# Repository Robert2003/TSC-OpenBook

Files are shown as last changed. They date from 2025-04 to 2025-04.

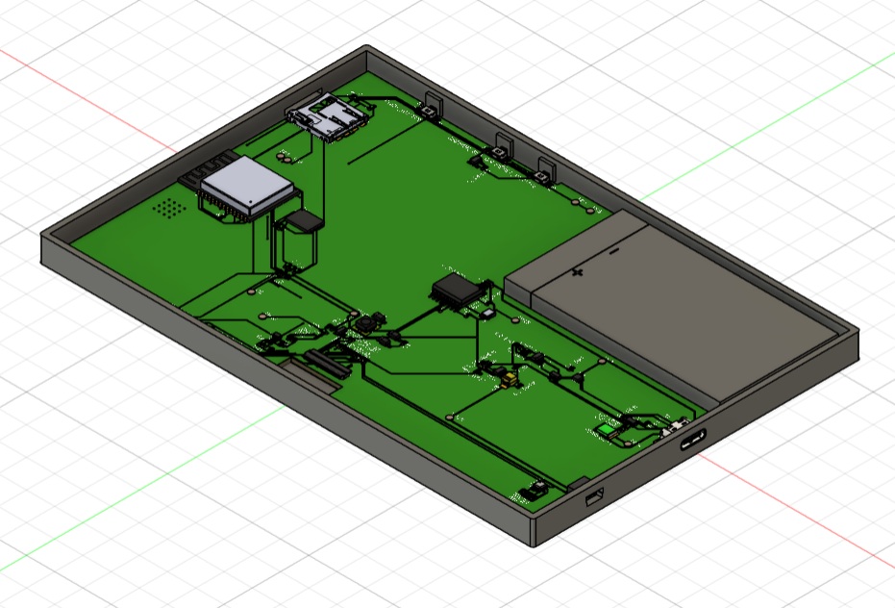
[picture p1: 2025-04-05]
Images/board_top_no_lid.jpg

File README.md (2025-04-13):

# README - OpenBook

## Diagrama bloc
```mermaid
graph LR;
    USB["USB-C Connector & ESD Protection"] -->|VBUS| CHG
    BATT["Li-Po Battery"] -->|VBAT| CHG["Battery Charging Controller (MCP73831)"]
    USB -->|VBUS pass-through| LDO["LDO Voltage Regulator (XC6220)"]
    USB -->|USB| ESP["ESP32-C6 MICROCONTROLLER Wi-Fi (MCU Central)"]
    CHG -->|VBAT| LDO
    LDO -->|3.3V| ESP["ESP32-C6 MICROCONTROLLER Wi-Fi (MCU Central)"]

    ESP -->|I2C| RTC["RTC Module (DS3231SN)"]
    ESP -->|I2C| BME["Environmental Sensor (BME680)"]

    ESP -->|SPI| FLASH["External NOR Flash (W25Q512)"]
    ESP -->|SPI| EPD_HEADER["E-Paper Display Header"]
    ESP -->|SPI| SD["MicroSD Card"]
    ESP -->|GPIO| BUTTONS["BOOT, CHANGE, RESET Buttons"]
    ESP -->|GPIO| VSUP["Voltage Supervisor + Reset/Boot IO"]

    EPD_HEADER -->|Power, SPI| EPD_DRIVER["E-Paper Drive Circuit"]
    EPD_DRIVER -->|Type Config| DISP_SEL["Display Type Selector"]
    EPD_DRIVER -->|High Voltage| EPD_POW["EPD Power Circuit"]

    I2C_CONN["Qwiic / Stemma QT"] -->|I2C| ESP
    BAT_LVL["Battery Charge Level"] -->|I2C| ESP
    SERCOM["RX/TX Serial Communication"] --> ESP
```
---

## Funcționalitatea hardware

### Microcontroller principal
- ESP32-C6-WROOM-1-N8
  - Procesor RISC-V 32-bit
  - Conectivitate Wi-Fi 6 și Bluetooth 5.0
  - 8MB Flash (intern)
  - Alimentare 3.3V
  - Niveluri logice 3.3V

### Componente periferice și interfețe

| Componentă | Ref. Schematică | Interfață | Pini ESP32 Utilizați / Descriere |
| :--- | :--- | :--- | :--- |
| Ecran EPD (e-paper) | J4 | SPI + GPIO | SPI (IO7, IO27, IO6), CS (IO11), DC (IO5), RST (IO21), BUSY (IO26) |
| Slot Card MicroSD | J3 | SPI | SPI (IO7=MOSI/DI, IO27=MISO/DO, IO6=SCK), CS (IO10) |
| Interfață USB | J2 | USB Native | D- (IO13), D+ (IO14) via protecție ESD (D2) |
| RTC (Real Time Clock) | IC2 | I2C | SDA (IO19), SCL (IO20); Include Supercap (C10) pentru backup |
| Senzor Temp/Umid/Pres/Gaz (BME) | IC3 | I2C | SDA (IO19), SCL (IO20) |
| Încărcător Li-Po | IC1 | Power | MCP73831; Indicator LED încărcare (D4) |
| Regulator LDO 3.3V | IC4 | Power | XC6220A331MR-G |
| Circuit Reset / Supraveghere | IC5 | Power/Control| BD5229G-TR |
| Buton BOOT | SW1 | GPIO | Conectat la IO8 |
| Buton RESET | SW2 | Reset | Conectat la linia RESET |
| MOSFET comutare EPD Power | Q1, Q2 | Control | Comută alimentarea 3V3_EPD |

#### SPI (Serial Peripheral Interface)
- **Utilizat pentru EPD și Card SD.**
- **MOSI** (Master Out Slave In): **IO7**
- **MISO** (Master In Slave Out): **IO27**
- **SCK** (Serial Clock): **IO6**
- **SS / CS** (Slave Select / Chip Select):
    - **EPD_CS**: **IO11**
    - **SD_CS**: **IO10**

#### I2C (Inter-Integrated Circuit)
- **Utilizat pentru RTC (IC2) și Senzor BME (IC3).**
- **SDA** (Serial Data): **IO19**
- **SCL** (Serial Clock): **IO20**

#### GPIO (General Purpose Input/Output) & Alți Pini
- **EPD_DC** (Data/Command): **IO5**
- **EPD_RST** (Reset): **IO21**
- **EPD_BUSY**: **IO26**
- **USB_D-**: **IO13**
- **USB_D+**: **IO14**
- **BOOT_PIN**: **IO8**
- **RESET_PIN**: **IO3**
- **EN** (Enable): Conectat la 3.3V

## Detaliere Pini Utilizați (ESP32-C6 / U2)

| Pin ESP32 | Funcție Principală | Componentă Conectată / Scop |
| :--- | :--- | :--- |
| IO0 | GPIO | INT_RTC (ieșire din RTC) |
| IO1 | GPIO | 32KHZ (ieșire ceas RTC) |
| IO2 | SPI MISO | MISO (EPD + SD) |
| IO3 | GPIO | SS_SD (chip select pentru SD) |
| IO4 | GPIO | EPD_BUSY |
| IO5 | GPIO | EPD_DC |
| IO6 | SPI SCK | SCK (EPD + SD) |
| IO7 | SPI MOSI | MOSI (EPD + SD) |
| IO8 | GPIO | IO/BOOT (buton boot) |
| IO10 | GPIO | EPD_CS |
| IO11 | GPIO | FLASH_CS |
| IO12 | GPIO | Neutilizat |
| IO13 | USB D- | USB_D- (conector USB-C) |
| IO14 | USB D+ | USB_D+ (conector USB-C) |
| IO16 | UART TX | TX |
| IO17 | UART RX | RX |
| IO18 | GPIO | RTC_RST |
| IO19 | GPIO | I2C_PW (putere I2C) |
| IO20 | I2C SDA | SDA (RTC + BME280) |
| IO21 | I2C SCL | SCL (RTC + BME280) |
| IO22 | GPIO | EPD_RST |
| IO23 | GPIO | Neconectat |
| IO25 | GPIO | IO/CHANGE |
| IO26 | GPIO | EPD_BUSY |
| IO27 | SPI MISO | 32KHZ (ceas RTC) |
| EN | Enable | Buton RESET (pull-up la 3.3V) |
| VDD (3V3) | Alimentare | 3.3V |
| GND | Masă | GND |

---

##  Bill of Materials

| Device | Datasheet | Purchase URL |
| :--- | :--- | :--- |
| ADAFRUIT_LEDCHIP-LED0603 | [Datasheet](https://www.mouser.com/datasheet/2/423/LSM0603472V_(1)-1379786.pdf) | [Purchase](https://componentsearchengine.com/part-view/LSM0603463V/Visual%20Communications%20Company) |
| BUTTON_CUSYOMV1 | [Datasheet](https://industry.panasonic.com/global/en/downloads?tab=catalog&small_g_cd=203&part_no=EVQPUJ02K) | [Purchase](https://industry.panasonic.com/global/en/products/control/switch/light-touch/number/evqpuj02k) |
| ESP32C6_VARISTORCN1812 | [Datasheet](https://www.tdk-electronics.tdk.com/inf/75/db/CTVS_14/Surge_protection_series.pdf) | [Purchase](https://www.mouser.co.uk/ProductDetail/EPCOS-TDK/B72520T0350K062?qs=dEfas%2FXlABIszF52uu7vrg%3D%3D) |
| ESP32_WROVER_SPARKFUN-IC-POWER_MCP73831 | [Datasheet](https://ro.mouser.com/datasheet/2/268/MCP73831_Family_Data_Sheet_DS20001984H-3441711.pdf) | [Purchase](https://ro.mouser.com/ProductDetail/Microchip-Technology/MCP73831T-5ACI-OT?qs=hH%252BOa0VZEiAcgAcEkuamXg%3D%3D) |
| SAMACSYS_PARTS_USB4110-GF-A | [Datasheet](https://ro.mouser.com/datasheet/2/837/GCT_USB4110_Product_Drawing___20k_cycles-3455479.pdf) | [Purchase](https://componentsearchengine.com/part-view/XC6220A331MR-G/Torex) |
| SJ | [Datasheet](https://analytics.supplyframe.com/trackingservlet/track/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) | [Purchase](https://componentsearchengine.com/part-view/R0402%201%25%20100%20K%20(RC0402FR-07100KL)/YAGEO) |
| ESP32_WROVER_EAGLE-LTSPICE_RR0402 | [Datasheet](https://analytics.supplyframe.com/trackingservlet/track/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) | [Purchase](https://componentsearchengine.com/part-view/R0402%201%25%20100%20K%20(RC0402FR-07100KL)/YAGEO) |
| ESP32_WROVER_EAGLE-LTSPICE_RR0402 | [Datasheet](https://analytics.supplyframe.com/trackingservlet/track/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) | [Purchase](https://componentsearchengine.com/part-view/R0402%201%25%20100%20K%20(RC0402FR-07100KL)/YAGEO) |
| EAGLE-LTSPICE_CC0402 | [Datasheet](https://ro.mouser.com/datasheet/2/447/UPY_GP_NP0_16V_to_50V_18-1730511.pdf) | [Purchase](https://componentsearchengine.com/part-view/0805Y2500471FCR/Knowles) |
| RCL_CPOL-EUCT3528 | [Datasheet](https://analytics.supplyframe.com/trackingservlet/track/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) | [Purchase](https://componentsearchengine.com/part-view/0805Y2500471FCR/Knowles) |
| ESP32_WROVER_EAGLE-LTSPICE_RR0402 | [Datasheet](https://analytics.supplyframe.com/trackingservlet/track/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) | [Purchase](https://componentsearchengine.com/part-view/R0402%201%25%20100%20K%20(RC0402FR-07100KL)/YAGEO) |
| ESP32_WROVER_EAGLE-LTSPICE_RR0402 | [Datasheet](https://analytics.supplyframe.com/trackingservlet/track/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) | [Purchase](https://componentsearchengine.com/part-view/R0402%201%25%20100%20K%20(RC0402FR-07100KL)/YAGEO) |
| EAGLE-LTSPICE_CC0402 | [Datasheet](https://analytics.supplyframe.com/trackingservlet/track/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) | [Purchase](https://componentsearchengine.com/part-view/0805Y2500471FCR/Knowles) |
| 112A-TAAR-R03_ATTEND | [Datasheet](https://www.attend.com.tw/data/download/file/112A-TAAR-R03_Spec.pdf) | [Purchase](https://store.comet.srl.ro/Catalogue/Product/43497/) |
| ESP32_WROVER_EAGLE-LTSPICE_RR0402 | [Datasheet](https://analytics.supplyframe.com/trackingservlet/track/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) | [Purchase](https://componentsearchengine.com/part-view/R0402%201%25%20100%20K%20(RC0402FR-07100KL)/YAGEO) |
| EAGLE-LTSPICE_CC0402 | [Datasheet](https://analytics.supplyframe.com/trackingservlet/track/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) | [Purchase](https://componentsearchengine.com/part-view/0805Y2500471FCR/Knowles) |
| EAGLE-LTSPICE_CC0402 | [Datasheet](https://analytics.supplyframe.com/trackingservlet/track/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) | [Purchase](https://componentsearchengine.com/part-view/0805Y2500471FCR/Knowles) |
| ESP32_WROVER_EAGLE-LTSPICE_RR0402 | [Datasheet](https://analytics.supplyframe.com/trackingservlet/track/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) | [Purchase](https://componentsearchengine.com/part-view/R0402%201%25%20100%20K%20(RC0402FR-07100KL)/YAGEO) |
| ESP32_WROVER_EAGLE-LTSPICE_RR0402 | [Datasheet](https://analytics.supplyframe.com/trackingservlet/track/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) | [Purchase](https://componentsearchengine.com/part-view/R0402%201%25%20100%20K%20(RC0402FR-07100KL)/YAGEO) |
| ESP32_WROVER_SPARKFUN-DISCRETESEMI_MOSFET_PCH-DMG2305UX-7 | [Datasheet](https://analytics.supplyframe.com/trackingservlet/track/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) | [Purchase](https://componentsearchengine.com/part-view/DMG2305UX-7/Diodes%20Incorporated) |
| ESP32_WROVER_EAGLE-LTSPICE_RR0402 | [Datasheet](https://analytics.supplyframe.com/trackingservlet/track/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) | [Purchase](https://componentsearchengine.com/part-view/R0402%201%25%20100%20K%20(RC0402FR-07100KL)/YAGEO) |
| EAGLE-LTSPICE_CC0402 | [Datasheet](https://analytics.supplyframe.com/trackingservlet/track/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) | [Purchase](https://componentsearchengine.com/part-view/0805Y2500471FCR/Knowles) |
| EAGLE-LTSPICE_CC0402 | [Datasheet](https://analytics.supplyframe.com/trackingservlet/track/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) | [Purchase](https://componentsearchengine.com/part-view/0805Y2500471FCR/Knowles) |
| ESP32_WROVER_EAGLE-LTSPICE_RR0402 | [Datasheet](https://analytics.supplyframe.com/trackingservlet/track/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) | [Purchase](https://componentsearchengine.com/part-view/R0402%201%25%20100%20K%20(RC0402FR-07100KL)/YAGEO) |
| 744043680IND_4828-WE-TPC_WRE | [Datasheet](https://www.we-online.com/components/products/datasheet/744043680.pdf) | [Purchase](https://eu.mouser.com/ProductDetail/Wurth-Elektronik/744043680?qs=PGXP4M47uW6VkZq%252BkzjrHA%3D%3D) |
| BD5229G-TR | [Datasheet](https://analytics.supplyframe.com/trackingservlet/track/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) | [Purchase](https://componentsearchengine.com/part-view/BD5229G-TR/ROHM%20Semiconductor) |
| ESP32_WROVER_BME680_BME680 | [Datasheet](https://www.snapeda.com/parts/BME680/Bosch%20Sensortec/datasheet/) | [Purchase](https://www.snapeda.com/parts/BME680/Bosch/view-part/?welcome=home) |
| CPH3225A | [Datasheet](https://www.snapeda.com/parts/CPH3225A/Seiko%20Instruments/datasheet/) | [Purchase](https://www.snapeda.com/parts/CPH3225A/Seiko+Instruments/view-part/?ref=eda) |
| DS3231SN# | [Datasheet](https://www.snapeda.com/parts/DS3231SN%23/Analog%20Devices/datasheet/) | [Purchase](https://www.snapeda.com/parts/DS3231SN%23/Analog+Devices/view-part/?ref=eda) |
| ESP32-C6-WROOM-1-N8 | [Datasheet](https://www.snapeda.com/parts/ESP32-C6-WROOM-1-N8/Espressif%20Systems/datasheet/) | [Purchase](https://www.snapeda.com/parts/ESP32-C6-WROOM-1-N8/Espressif+Systems/view-part/?ref=eda) |
| FH34SRJ-24S-0.5SH_99_ | [Datasheet](https://analytics.supplyframe.com/trackingservlet/track/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) | [Purchase](https://componentsearchengine.com/part-view/XC6220A331MR-G/Torex) |
| MAX17048G+T10 | [Datasheet](https://www.snapeda.com/parts/MAX17048G+T10/Analog%20Devices/datasheet/) | [Purchase](https://www.snapeda.com/parts/MAX17048G+T10/Analog+Devices/view-part/?ref=eda) |
| MBR0530 | [Datasheet](https://ro.mouser.com/datasheet/2/40/schottky-3165252.pdf) | [Purchase](https://eu.mouser.com/ProductDetail/KYOCERA-AVX/SD0805S020S1R0?qs=jCA%252BPfw4LHbpkAoSnwrdjw%3D%3D) |
| PGB1010603MR | [Datasheet](https://www.snapeda.com/parts/PGB1010603MR/Littelfuse%20Inc./datasheet/) | [Purchase](https://www.snapeda.com/parts/PGB1010603MR/Littelfuse/view-part/?ref=eda) |
| QWIIC_CONNECTORJS-1MM | [Datasheet](https://www.attend.com.tw/data/download/file/112A-TAAR-R03_Spec.pdf) | [Purchase](https://eu.mouser.com/ProductDetail/Adafruit/4208?qs=PzGy0jfpSMtbScLbr0L5dw%3D%3D) |
| ESP32_WROVER_AVX---SD0805S020S1R0_AVX_SD0805S020S1R0_0_0AVX_SD0805S020S1R0_0_0 | [Datasheet](http://datasheets.avx.com/schottky.pdf) | [Purchase](https://eu.mouser.com/ProductDetail/KYOCERA-AVX/SD0805S020S1R0?qs=jCA%252BPfw4LHbpkAoSnwrdjw%3D%3D) |
| SI1308EDL-T1-GE3 | [Datasheet](https://analytics.supplyframe.com/trackingservlet/track/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) | [Purchase](https://componentsearchengine.com/part-view/SI1308EDL-T1-GE3/Vishay) |
| TPTP20R | - | - |
| USBLC6-2SC6Y | [Datasheet](https://www.snapeda.com/parts/USBLC6-2SC6Y/STMicroelectronics/datasheet/) | [Purchase](https://www.snapeda.com/parts/USBLC6-2SC6Y/STMicroelectronics/view-part/?ref=eda) |
| W25Q512JVEIQ | [Datasheet](https://www.snapeda.com/parts/W25Q512JVEIQ/Winbond%20Electronics/datasheet/) | [Purchase](https://www.snapeda.com/parts/W25Q512JVEIQ/Winbond+Electronics/view-part/?ref=eda) |
| XC6220A331MR-G | [Datasheet](https://www.snapeda.com/parts/W25Q512JVEIQ/Winbond%20Electronics/datasheet/) | [Purchase](https://componentsearchengine.com/part-view/XC6220A331MR-G/Torex) |

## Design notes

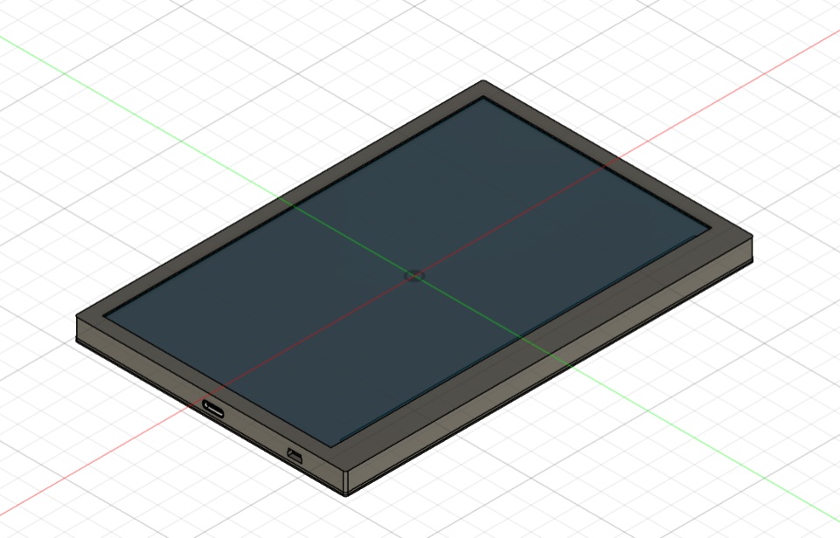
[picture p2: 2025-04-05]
Images/board_bottom.jpg

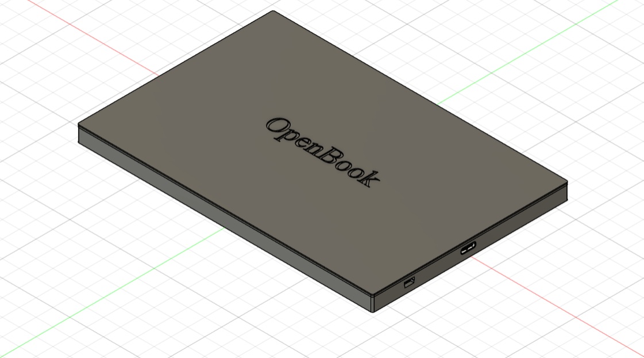
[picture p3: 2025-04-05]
Images/board_top_lid.jpg

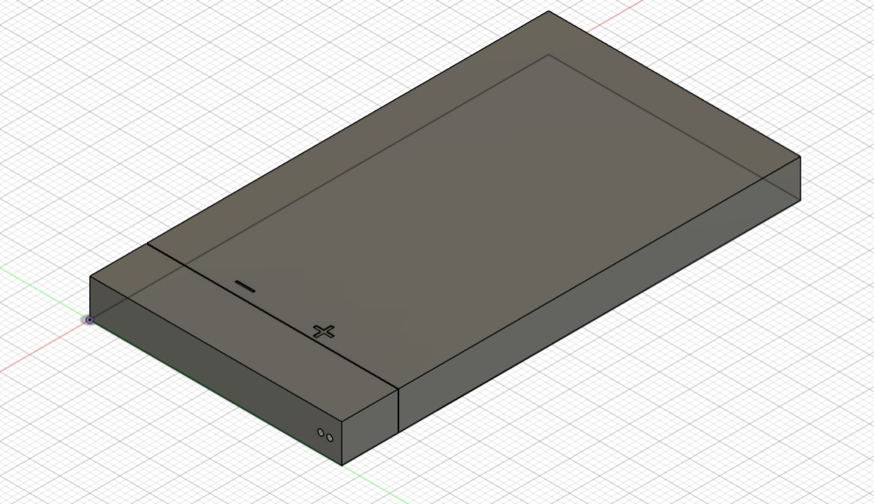
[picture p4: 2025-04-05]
Images/battery.jpg

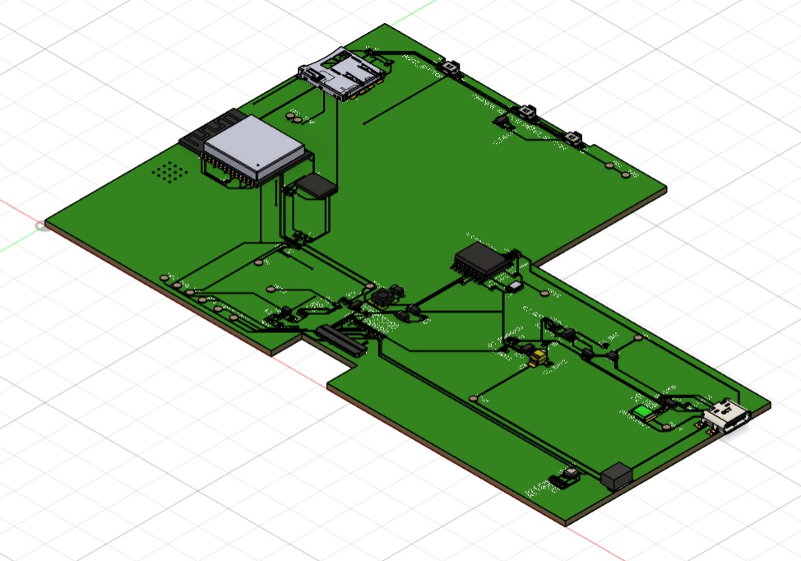
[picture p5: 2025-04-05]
Images/pcb.jpg

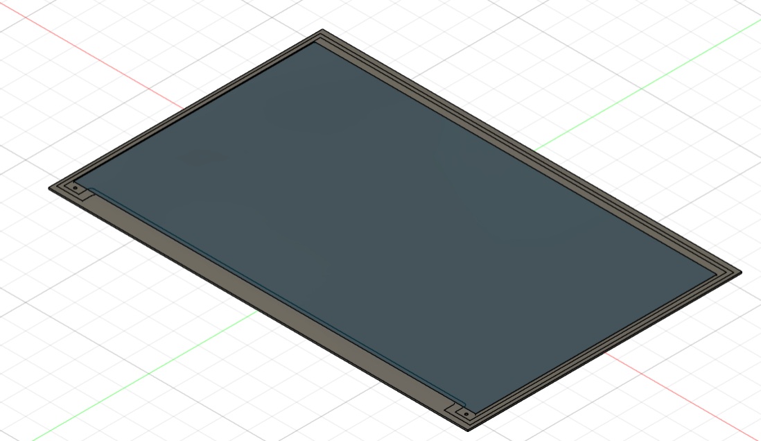
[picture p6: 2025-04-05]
Images/screen.jpg

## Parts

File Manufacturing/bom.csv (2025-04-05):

Qty | Value | Device | Package | Parts | Description | ARROW_PART_NUMBER | ARROW_PRICE-STOCK | AVAILABILITY | CENTROID_NOT_SPECIFIED | CHECK_PRICES | COPYRIGHT | DATASHEET | DESCRIPTION | DIGIKEY_DESCRIPTION | DIGIKEY_PART_NUMBER | HEIGHT | LEAD_FREE | MANUFACTURER_NAME | MANUFACTURER_PART_NUMBER | MF | MFR_NAME | MOUSER_PART_NUMBER | MOUSER_PRICE-STOCK | MOUSER_TESTING_PART_NUMBER | MOUSER_TESTING_PRICE-STOCK | MP | MPN | PACKAGE | POPULARITY | PREFIX | PRICE | PROD_ID | PURCHASE-URL | ROHS | SNAPEDA_LINK | SPICEMODEL | SPICEPREFIX | TEMPERATURE_RANGE_HIGH | TEMPERATURE_RANGE_LOW | TP_SIGNAL_NAME | VALUE
1 |  | ADAFRUIT_LEDCHIP-LED0603 | ADAFRUIT_CHIP-LED0603 | CHG_LED | LED |  |  |  |  |  |  | https://analytics.supplyframe.com/trackingservlet/track/ |  |  |  |  |  |  |  |  |  |  |  |  |  |  |  |  |  |  |  |  | https://componentsearchengine.com/part-view/LSM0603463V/Visual%20Communications%20Company
3 |  | BUTTON_CUSYOMV1 | MYBUTTON | BOOT_BUTTON, CHANGE_BUTTON, RESET_BUTTON |  |  |  |  |  |  |  | https://industry.panasonic.com/global/en/downloads?tab=catalog&small_g_cd=203&part_no=EVQPUJ02K |  |  |  |  |  |  |  |  |  |  |  |  |  |  |  |  |  |  |  |  | https://industry.panasonic.com/global/en/products/control/switch/light-touch/number/evqpuj02k
1 |  | ESP32C6_VARISTORCN1812 | ESP32C6_VARISTOR_CT/CN1812 | PFMF.050.1 | VARISTOR |  |  |  |  |  |  | https://www.tdk-electronics.tdk.com/inf/75/db/CTVS_14/Surge_protection_series.pdf |  |  |  |  |  |  |  |  |  |  |  |  |  |  |  |  | 0 |  |  |  | https://www.mouser.co.uk/ProductDetail/EPCOS-TDK/B72520T0350K062?qs=dEfas%2FXlABIszF52uu7vrg%3D%3D
1 |  | ESP32_WROVER_SPARKFUN-IC-POWER_MCP73831 | ESP32_WROVER_SPARKFUN-IC-POWER_SOT23-5 | MCP73831 | MCP73831T Li-Ion, Li-Pol Controller |  |  |  |  |  |  | https://ro.mouser.com/datasheet/2/268/MCP73831_Family_Data_Sheet_DS20001984H-3441711.pdf |  |  |  |  |  |  |  |  |  |  |  |  |  |  |  |  |  |  |  | IC-09995 | https://ro.mouser.com/ProductDetail/Microchip-Technology/MCP73831T-5ACI-OT?qs=hH%252BOa0VZEiAcgAcEkuamXg%3D%3D
1 |  | SAMACSYS_PARTS_USB4110-GF-A | SAMACSYS_PARTS_USB4110GFA | J2 | CONN USB 2.0 TYPE-C R/A SMT |  |  |  |  |  |  | https://ro.mouser.com/datasheet/2/837/GCT_USB4110_Product_Drawing___20k_cycles-3455479.pdf | CONN USB 2.0 TYPE-C R/A SMT |  |  | 3.26mm |  | GCT (GLOBAL CONNECTOR TECHNOLOGY) | USB4110-GF-A |  |  | 640-USB4110-GF-A |  |  |  |  |  |  |  |  |  |  | https://componentsearchengine.com/part-view/XC6220A331MR-G/Torex
1 |  | SJ | ESP32_WROVER_EAGLE-LTSPICE_R0402 | SJ1 | SMD solder JUMPER |  |  |  |  |  |  | https://analytics.supplyframe.com/trackingservlet/track/ |  |  |  |  |  |  |  |  |  |  |  |  |  |  |  |  | 3 |  |  |  | https://componentsearchengine.com/part-view/R0402%201%25%20100%20K%20(RC0402FR-07100KL)/YAGEO
1 | 0.47 | ESP32_WROVER_EAGLE-LTSPICE_RR0402 | ESP32_WROVER_EAGLE-LTSPICE_R0402 | R3 | RESISTOR, European symbol |  |  |  |  |  |  | https://analytics.supplyframe.com/trackingservlet/track/ |  |  |  |  |  |  |  |  |  |  |  |  |  |  |  |  |  |  |  |  | https://componentsearchengine.com/part-view/R0402%201%25%20100%20K%20(RC0402FR-07100KL)/YAGEO |  |  | NONE | R
1 | 100K | ESP32_WROVER_EAGLE-LTSPICE_RR0402 | ESP32_WROVER_EAGLE-LTSPICE_R0402 | R1_PWRUSB | RESISTOR, European symbol |  |  |  |  |  |  | https://analytics.supplyframe.com/trackingservlet/track/ |  |  |  |  |  |  |  |  |  |  |  |  |  |  |  |  |  |  |  |  | https://componentsearchengine.com/part-view/R0402%201%25%20100%20K%20(RC0402FR-07100KL)/YAGEO |  |  | NONE | R
8 | 100nF | EAGLE-LTSPICE_CC0402 | EAGLE-LTSPICE_C0402 | C1, C2, C4_USB, C6, C8, C9, C10, C_DELAY | CAPACITOR, European symbol |  |  |  |  |  |  | https://analytics.supplyframe.com/trackingservlet/track/ |  |  |  |  |  |  |  |  |  |  |  |  |  |  |  |  |  |  |  |  | https://componentsearchengine.com/part-view/0805Y2500471FCR/Knowles |  |  | NONE | C
1 | 100uF TANT | RCL_CPOL-EUCT3528 | RCL_CT3528 | C3 | POLARIZED CAPACITOR, European symbol |  |  |  |  |  |  | https://analytics.supplyframe.com/trackingservlet/track/ |  |  |  |  |  |  |  |  |  |  |  |  |  |  |  |  | 0 |  |  |  | https://componentsearchengine.com/part-view/0805Y2500471FCR/Knowles |  |  |  | C
15 | 10K | ESP32_WROVER_EAGLE-LTSPICE_RR0402 | ESP32_WROVER_EAGLE-LTSPICE_R0402 | R1_PINH, R1_PINH1, R2-PINH, R2-PINH1, R4, R5, R6, R7, R8, R9, R10, R_BOOT, R_CHANGE, R_CL1, R_RESET | RESISTOR, European symbol |  |  |  |  |  |  | https://analytics.supplyframe.com/trackingservlet/track/ |  |  |  |  |  |  |  |  |  |  |  |  |  |  |  |  |  |  |  |  | https://componentsearchengine.com/part-view/R0402%201%25%20100%20K%20(RC0402FR-07100KL)/YAGEO |  |  | NONE | R
1 | 10k | ESP32_WROVER_EAGLE-LTSPICE_RR0402 | ESP32_WROVER_EAGLE-LTSPICE_R0402 | R1 | RESISTOR, European symbol |  |  |  |  |  |  | https://analytics.supplyframe.com/trackingservlet/track/ |  |  |  |  |  |  |  |  |  |  |  |  |  |  |  |  |  |  |  |  | https://componentsearchengine.com/part-view/R0402%201%25%20100%20K%20(RC0402FR-07100KL)/YAGEO |  |  | NONE | R
1 | 10uF | EAGLE-LTSPICE_CC0402 | EAGLE-LTSPICE_C0402 | C7 | CAPACITOR, European symbol |  |  |  |  |  |  | https://analytics.supplyframe.com/trackingservlet/track/ |  |  |  |  |  |  |  |  |  |  |  |  |  |  |  |  |  |  |  |  | https://componentsearchengine.com/part-view/0805Y2500471FCR/Knowles |  |  | NONE | C
1 | 112A-TAAR-R03_ATTEND | 112A-TAAR-R03_ATTEND | 112ATAARR03ATTEND | J4 | Micro SD Card Socket, Push-Push Type, Top Mount, SMT, H=1.83mm, 10u |  |  |  |  |  |  |  | Micro SD Card Socket | Push-Push Type | Top Mount | SMT | H=1.83mm | 10u |  |  | 1.9mm |  | ATTEND | 112A-TAAR-R03 ATTEND |  |  |  |  |  |  |  |  | https://store.comet.srl.ro/Catalogue/Product/43497/
1 | 15 | ESP32_WROVER_EAGLE-LTSPICE_RR0402 | ESP32_WROVER_EAGLE-LTSPICE_R0402 | R_CAPACITOR | RESISTOR, European symbol |  |  |  |  |  |  | https://analytics.supplyframe.com/trackingservlet/track/ |  |  |  |  |  |  |  |  |  |  |  |  |  |  |  |  |  |  |  |  | https://componentsearchengine.com/part-view/R0402%201%25%20100%20K%20(RC0402FR-07100KL)/YAGEO |  |  | NONE | R
1 | 1uF | EAGLE-LTSPICE_CC0402 | EAGLE-LTSPICE_C0402 | C5 | CAPACITOR, European symbol |  |  |  |  |  |  | https://analytics.supplyframe.com/trackingservlet/track/ |  |  |  |  |  |  |  |  |  |  |  |  |  |  |  |  |  |  |  |  | https://componentsearchengine.com/part-view/0805Y2500471FCR/Knowles |  |  | NONE | C
10 | 1uF/50V | EAGLE-LTSPICE_CC0402 | EAGLE-LTSPICE_C0402 | EPD_C1, EPD_C2, EPD_C5, EPD_C6, EPD_C7, EPD_C8, EPD_C9, EPD_C10, EPD_C11, EPD_C12 | CAPACITOR, European symbol |  |  |  |  |  |  | https://analytics.supplyframe.com/trackingservlet/track/ |  |  |  |  |  |  |  |  |  |  |  |  |  |  |  |  |  |  |  |  | https://componentsearchengine.com/part-view/0805Y2500471FCR/Knowles |  |  | NONE | C
1 | 2.2 | ESP32_WROVER_EAGLE-LTSPICE_RR0402 | ESP32_WROVER_EAGLE-LTSPICE_R0402 | R2 | RESISTOR, European symbol |  |  |  |  |  |  | https://analytics.supplyframe.com/trackingservlet/track/ |  |  |  |  |  |  |  |  |  |  |  |  |  |  |  |  |  |  |  |  | https://componentsearchengine.com/part-view/R0402%201%25%20100%20K%20(RC0402FR-07100KL)/YAGEO |  |  | NONE | R
1 | 200 | ESP32_WROVER_EAGLE-LTSPICE_RR0402 | ESP32_WROVER_EAGLE-LTSPICE_R0402 | R1_BAT | RESISTOR, European symbol |  |  |  |  |  |  | https://analytics.supplyframe.com/trackingservlet/track/ |  |  |  |  |  |  |  |  |  |  |  |  |  |  |  |  |  |  |  |  | https://componentsearchengine.com/part-view/R0402%201%25%20100%20K%20(RC0402FR-07100KL)/YAGEO |  |  | NONE | R
2 | 20V/4.2A/52mO/1.4W | ESP32_WROVER_SPARKFUN-DISCRETESEMI_MOSFET_PCH-DMG2305UX-7 | ESP32_WROVER_SPARKFUN-DISCRETESEMI_SOT23-3 | Q1, Q2 | P-channel MOSFETs |  |  |  |  |  |  | https://analytics.supplyframe.com/trackingservlet/track/ |  |  |  |  |  |  |  |  |  |  |  |  |  |  |  |  |  |  |  | TRAN-14388 | https://componentsearchengine.com/part-view/DMG2305UX-7/Diodes%20Incorporated |  |  |  |  |  |  |  | 20V/4.2A/52mO/1.4W
1 | 2k | ESP32_WROVER_EAGLE-LTSPICE_RR0402 | ESP32_WROVER_EAGLE-LTSPICE_R0402 | R2_BAT | RESISTOR, European symbol |  |  |  |  |  |  | https://analytics.supplyframe.com/trackingservlet/track/ |  |  |  |  |  |  |  |  |  |  |  |  |  |  |  |  |  |  |  |  | https://componentsearchengine.com/part-view/R0402%201%25%20100%20K%20(RC0402FR-07100KL)/YAGEO |  |  | NONE | R
5 | 4.7uF | EAGLE-LTSPICE_CC0402 | EAGLE-LTSPICE_C0402 | C1_BAT, C1_BAT1, C1_BAT2, C2_BAT, C5_USB | CAPACITOR, European symbol |  |  |  |  |  |  | https://analytics.supplyframe.com/trackingservlet/track/ |  |  |  |  |  |  |  |  |  |  |  |  |  |  |  |  |  |  |  |  | https://componentsearchengine.com/part-view/0805Y2500471FCR/Knowles |  |  | NONE | C
1 | 4.7uF/25V | EAGLE-LTSPICE_CC0402 | EAGLE-LTSPICE_C0402 | C4 | CAPACITOR, European symbol |  |  |  |  |  |  | https://analytics.supplyframe.com/trackingservlet/track/ |  |  |  |  |  |  |  |  |  |  |  |  |  |  |  |  |  |  |  |  | https://componentsearchengine.com/part-view/0805Y2500471FCR/Knowles |  |  | NONE | C
2 | 5k1 | ESP32_WROVER_EAGLE-LTSPICE_RR0402 | ESP32_WROVER_EAGLE-LTSPICE_R0402 | R2-USB, R2-USB1 | RESISTOR, European symbol |  |  |  |  |  |  | https://analytics.supplyframe.com/trackingservlet/track/ |  |  |  |  |  |  |  |  |  |  |  |  |  |  |  |  |  |  |  |  | https://componentsearchengine.com/part-view/R0402%201%25%20100%20K%20(RC0402FR-07100KL)/YAGEO |  |  | NONE | R
1 | 68uH | 744043680IND_4828-WE-TPC_WRE | IND_4828-WE-TPC_WRE | L1 |  |  |  |  |  |  | Copyright (C) 2024 Ultra Librarian. All rights reserved. | https://www.we-online.com/components/products/datasheet/744043680.pdf |  |  |  |  |  |  | 744043680 |  | Wurth Electronics |  |  |  |  |  |  |  |  |  |  |  | https://eu.mouser.com/ProductDetail/Wurth-Elektronik/744043680?qs=PGXP4M47uW6VkZq%252BkzjrHA%3D%3D
1 | BD5229G-TR | BD5229G-TR | SOT95P280X125-5N | IC1 | Voltage Detector with Adjustable Delay Time: CMOS processes are utilized to develop high precision, low current consumption CMOS reset ICs that allow arbitrary setting of the delay time. The extensive lineup includes both Nch Open Drain and CMOS output types in a wide range of detection voltages (from 2.3V to 6.0V, in 0.1V steps), enabling selection of the ideal solution based on customer requirements. In addition, the entire series is of course both lead-free and RoHS-compliant. |  |  |  |  |  |  | https://analytics.supplyframe.com/trackingservlet/track/ | Voltage Detector with Adjustable Delay Time: CMOS processes are utilized to develop high precision | low current consumption CMOS reset ICs that allow arbitrary setting of the delay time. The extensive lineup includes both Nch Open Drain and CMOS output types in a wide range of detection voltages (from 2.3V to 6.0V | in 0.1V steps) | enabling selection of the ideal solution based on customer requirements. In addition | the entire series is of course both lead-free and RoHS-compliant. |  |  | 1.25mm |  | ROHM Semiconductor | BD5229G-TR |  |  | 755-BD5229G-TR |  |  |  |  |  |  | https://componentsearchengine.com/part-view/BD5229G-TR/ROHM%20Semiconductor
1 | BME688 | ESP32_WROVER_BME680_BME680 | ESP32_WROVER_BME680_PSON80P300X300X100-8N | SENSOR2 | Integrated Environmental Unit |  |  | Unavailable |  |  |  | https://www.snapeda.com/parts/BME680/Bosch%20Sensortec/datasheet/ | Integrated Environmental Unit |  |  |  |  |  |  | Bosch Sensortec |  |  |  |  |  | BME680 |  | LGA-8 Bosch Tools |  |  | None |  | https://www.snapeda.com/parts/BME680/Bosch/view-part/?welcome=home
1 | CPH3225A | CPH3225A | CAPCP3225X100N | C10_SUPERCAP | Cap 0.011F 3.3V 1210 Flat Check availability |  |  | Not in stock |  |  |  | https://www.snapeda.com/parts/CPH3225A/Seiko%20Instruments/datasheet/ | 11 mF (EDLC) Supercapacitor 3.3 V 1210 (3225 Metric) - - |  |  |  |  |  |  | Seiko Instruments |  |  |  |  |  | CPH3225A |  | 1210 Seiko |  |  | None |  | https://www.snapeda.com/parts/CPH3225A/Seiko+Instruments/view-part/?ref=eda
1 | DS3231SN# | DS3231SN# | SOIC127P1032X265-16N | U3 | Real Time Clock Serial 16-Pin SOIC W T/R Check availability |  |  | In Stock |  |  |  | https://www.snapeda.com/parts/DS3231SN%23/Analog%20Devices/datasheet/ | Extremely Accurate I涎-Integrated RTC/TCXO/Crystal |  |  |  |  |  |  | Analog Devices |  |  |  |  |  | DS3231SN# |  | SOIC-16 Maxim |  |  | None |  | https://www.snapeda.com/parts/DS3231SN%23/Analog+Devices/view-part/?ref=eda
1 | ESP32-C6-WROOM-1-N8 | ESP32-C6-WROOM-1-N8 | XCVR_ESP32-C6-WROOM-1-N8 | U2 | Check availability |  |  | In Stock |  |  |  | https://www.snapeda.com/parts/ESP32-C6-WROOM-1-N8/Espressif%20Systems/datasheet/ | Multiprotocol Modules ESP32-C6 module | Wi-Fi 6 in 2.4 GHz band | Bluetooth 5 | Zigbee 3.0 and Thread. ESP34-WROOM Compatible - ENGINEERING SAMPLE |  |  |  |  |  |  | Espressif Systems |  |  |  |  |  | ESP32-C6-WROOM-1-N8 |  | None |  | https://www.snapeda.com/parts/ESP32-C6-WROOM-1-N8/Espressif+Systems/view-part/?ref=eda | None
1 | FH34SRJ-24S-0.5SH_99_ | FH34SRJ-24S-0.5SH_99_ | FH34SRJ24S05SH99 | J1 | (0.50mm) Surface Mount, Right Angle |  |  |  |  |  |  | https://analytics.supplyframe.com/trackingservlet/track/ | 24 Position FFC | FPC Connector Contacts | (0.50mm) Surface Mount | Right Angle |  |  | 1.1mm |  | Hirose | FH34SRJ-24S-0.5SH(99) |  |  | 798-FH34SRJ24S05SH99 |  |  |  |  |  |  |  | https://componentsearchengine.com/part-view/XC6220A331MR-G/Torex
1 | MAX17048G+T10 | MAX17048G+T10 | SON50P200X200X80-9N | U4 | Check availability |  |  | In Stock |  |  |  | https://www.snapeda.com/parts/MAX17048G+T10/Analog%20Devices/datasheet/ | 3渙 1-Cell/2-Cell Fuel Gauge with ModelGauge |  |  |  |  |  |  | Analog Devices |  |  |  |  |  | MAX17048G+T10 |  | TDFN-8 Maxim |  |  | None |  | https://www.snapeda.com/parts/MAX17048G+T10/Analog+Devices/view-part/?ref=eda
3 | MBR0530 | MBR0530 | SOD3716X135N | D3, D4, D5 | ON SEMICONDUCTOR - MBR0530 - DIODE, SCHOTTKY, 0.5A, 30V, SOD-123 |  |  | In Stock |  |  |  | https://ro.mouser.com/datasheet/2/40/schottky-3165252.pdf | Diode Schottky 30 V 500mA Surface Mount SOD-123 |  |  |  |  |  |  | ON Semiconductor |  |  |  |  |  | MBR0530 |  | SOD-123-2 ON Semiconductor |  |  | None |  | https://eu.mouser.com/ProductDetail/KYOCERA-AVX/SD0805S020S1R0?qs=jCA%252BPfw4LHbpkAoSnwrdjw%3D%3D
6 | PGB1010603MR | PGB1010603MR | DIOC1608X36N | D6, D8, D9, D10, D11, D12 | Check availability |  |  | In Stock |  |  |  | https://www.snapeda.com/parts/PGB1010603MR/Littelfuse%20Inc./datasheet/ | 150V (Typ) Clamp - Ipp Tvs Diode Surface Mount 0603 (1608 Metric) |  |  |  |  |  |  | Littelfuse Inc. |  |  |  |  |  | PGB1010603MR |  | 0603 Littelfuse Inc. |  |  | None |  | https://www.snapeda.com/parts/PGB1010603MR/Littelfuse/view-part/?ref=eda
1 | QWIIC_RIGHT_ANGLE | QWIIC_CONNECTORJS-1MM | JST04_1MM_RA | J3 | SparkFun I2C Standard Qwiic Connector |  |  |  |  |  |  |  |  |  |  |  |  |  |  |  |  |  |  |  |  |  |  |  |  |  |  | CONN-13694 | https://eu.mouser.com/ProductDetail/Adafruit/4208?qs=PzGy0jfpSMtbScLbr0L5dw%3D%3D |  |  |  |  |  |  |  | QWIIC_RIGHT_ANGLE
2 | SD0805S020S1R0 | ESP32_WROVER_AVX---SD0805S020S1R0_AVX_SD0805S020S1R0_0_0AVX_SD0805S020S1R0_0_0 | ESP32_WROVER_AVX---SD0805S020S1R0_AVX_SD0805S020S1R0_0 | D2, D7 | Schottky Barrier Rectifier Diode |  |  |  | No |  |  | http://datasheets.avx.com/schottky.pdf |  | DIODE SCHOTTKY 20V 1A 0805 | 478-7800-1-ND |  | yes |  |  | AVX |  | 581-SD0805S020S1R0 |  |  |  |  |  | 0805 (2012 metric) |  | D |  |  | https://eu.mouser.com/ProductDetail/KYOCERA-AVX/SD0805S020S1R0?qs=jCA%252BPfw4LHbpkAoSnwrdjw%3D%3D | yes |  |  |  | +125蚓 | -55蚓
1 | SI1308EDL-T1-GE3 | SI1308EDL-T1-GE3 | SOT65P210X110-3N | Q3 | MOSFET N-Ch 30V 1.5A TrenchFET SC70 Vishay Si1308EDL-T1-GE3 N-channel MOSFET Transistor, 1.5 A, 30 V, 3-Pin SC-70 |  |  | In Stock |  |  |  | https://analytics.supplyframe.com/trackingservlet/track/ | Si1308EDL-T1-GE3 N-channel MOSFET Transistor | 1.5 A | 30 V | 3-Pin SC-70 | Siliconix / Vishay SI1308EDL-T1-GE3 |  |  |  |  |  |  | Vishay Siliconix |  |  |  |  |  | SI1308EDL-T1-GE3 |  | SOT-323 Vishay Semiconductor |  | https://componentsearchengine.com/part-view/SI1308EDL-T1-GE3/Vishay | None
17 | TPTP20R | TPTP20R | TP20R | TP1, TP2, TP3, TP4, TP5, TP6, TP7, TP8, TP9, TP10, TP11, TP12, TP13, TP14, TP15, TP16, TP17 | Test pad |  |  |  |  |  |  |  |  |  |  |  |  |  |  |  |  |  |  |  |  |  |  |  | 2 |  |  |  | Custom Model
1 | USBLC6-2SC6Y | USBLC6-2SC6Y | SOT95P280X145-6N | D1 | Low Cap. ESD Protection Auto SOT-23-6 STMicroelectronics USBLC6-2SC6Y, Dual Uni-Directional TVS Diode Array, 6-Pin SOT-23 |  |  | In Stock |  |  |  | https://www.snapeda.com/parts/USBLC6-2SC6Y/STMicroelectronics/datasheet/ | 17V Clamp 5A (8/20盜) Ipp Tvs Diode Surface Mount SOT-23-6 |  |  |  |  |  |  | STMicroelectronics |  |  |  |  |  | USBLC6-2SC6Y |  | SOT-23-6 STMicroelectronics |  |  | None |  | https://www.snapeda.com/parts/USBLC6-2SC6Y/STMicroelectronics/view-part/?ref=eda
1 | W25Q512JVEIQ | W25Q512JVEIQ | SON127P600X800X80-9N | U1 | Check availability |  |  | In Stock |  |  |  | https://www.snapeda.com/parts/W25Q512JVEIQ/Winbond%20Electronics/datasheet/ | FLASH - NOR Memory IC 512Mb (64M x 8) SPI - Quad I/O 133 MHz 8-WSON (8x6) |  |  |  |  |  |  | Winbond Electronics |  |  |  |  |  | W25Q512JVEIQ |  | Package |  |  | None |  | https://www.snapeda.com/parts/W25Q512JVEIQ/Winbond+Electronics/view-part/?ref=eda
1 | XC6220A331MR-G | XC6220A331MR-G | SOT95P280X120-5N | IC4 | LDO Voltage Regulators |  |  |  |  |  |  | https://www.snapeda.com/parts/W25Q512JVEIQ/Winbond%20Electronics/datasheet/ | LDO Voltage Regulators |  |  | 1.2mm |  | Torex | XC6220A331MR-G |  |  | 865-XC6220A331MR-G |  |  |  |  |  |  |  |  |  |  | https://componentsearchengine.com/part-view/XC6220A331MR-G/Torex

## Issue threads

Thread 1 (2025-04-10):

Schematic missing information

AndreiArmega, 2025-04-10:
### VBUS label
VBUS label from Voltage Regulator missaligned

### EPD_C5 capcitor
Wrong capacitance value on EPD_C5 capcaitor

### Q2 missing component name
Q2 component does not provide the component name

### Missing capacitor label
Voltage Supervisor + Reset & Boot/ IO Button missing capacitor label

### Schematic frame
Missing schematic name information

Closed 2025-04-13.

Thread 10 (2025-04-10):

Additional Info

AndreiArmega, 2025-04-10:
 Power/voltage/tolerance ratings not specified in schematic.
 Traceability markings (rev, date, name, etc) not provided .

Closed 2025-04-13.

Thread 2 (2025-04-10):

Missing silkscreen

AndreiArmega, 2025-04-10:
No silkscreen present on the 3d PCB model . Label overlapping components and missing names on the 2d PCB design.

Closed 2025-04-13.

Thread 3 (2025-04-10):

Polygon Pour

AndreiArmega, 2025-04-10:
Missing areas in Polygon Pour on the 2d PCB.

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

Closed 2025-04-13.

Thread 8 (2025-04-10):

README details

AndreiArmega, 2025-04-10:
### A few of the datasheets links are faulty
-  ADAFRUIT_LEDCHIP-LED0603
-  EAGLE-LTSPICE_CC0402
-  RCL_CPOL-EUCT3528
-  112A-TAAR-R03_ATTEND
-  QWIIC_CONNECTORJS-1MM

### Duplicate entries in the BOM table

Closed 2025-04-13.

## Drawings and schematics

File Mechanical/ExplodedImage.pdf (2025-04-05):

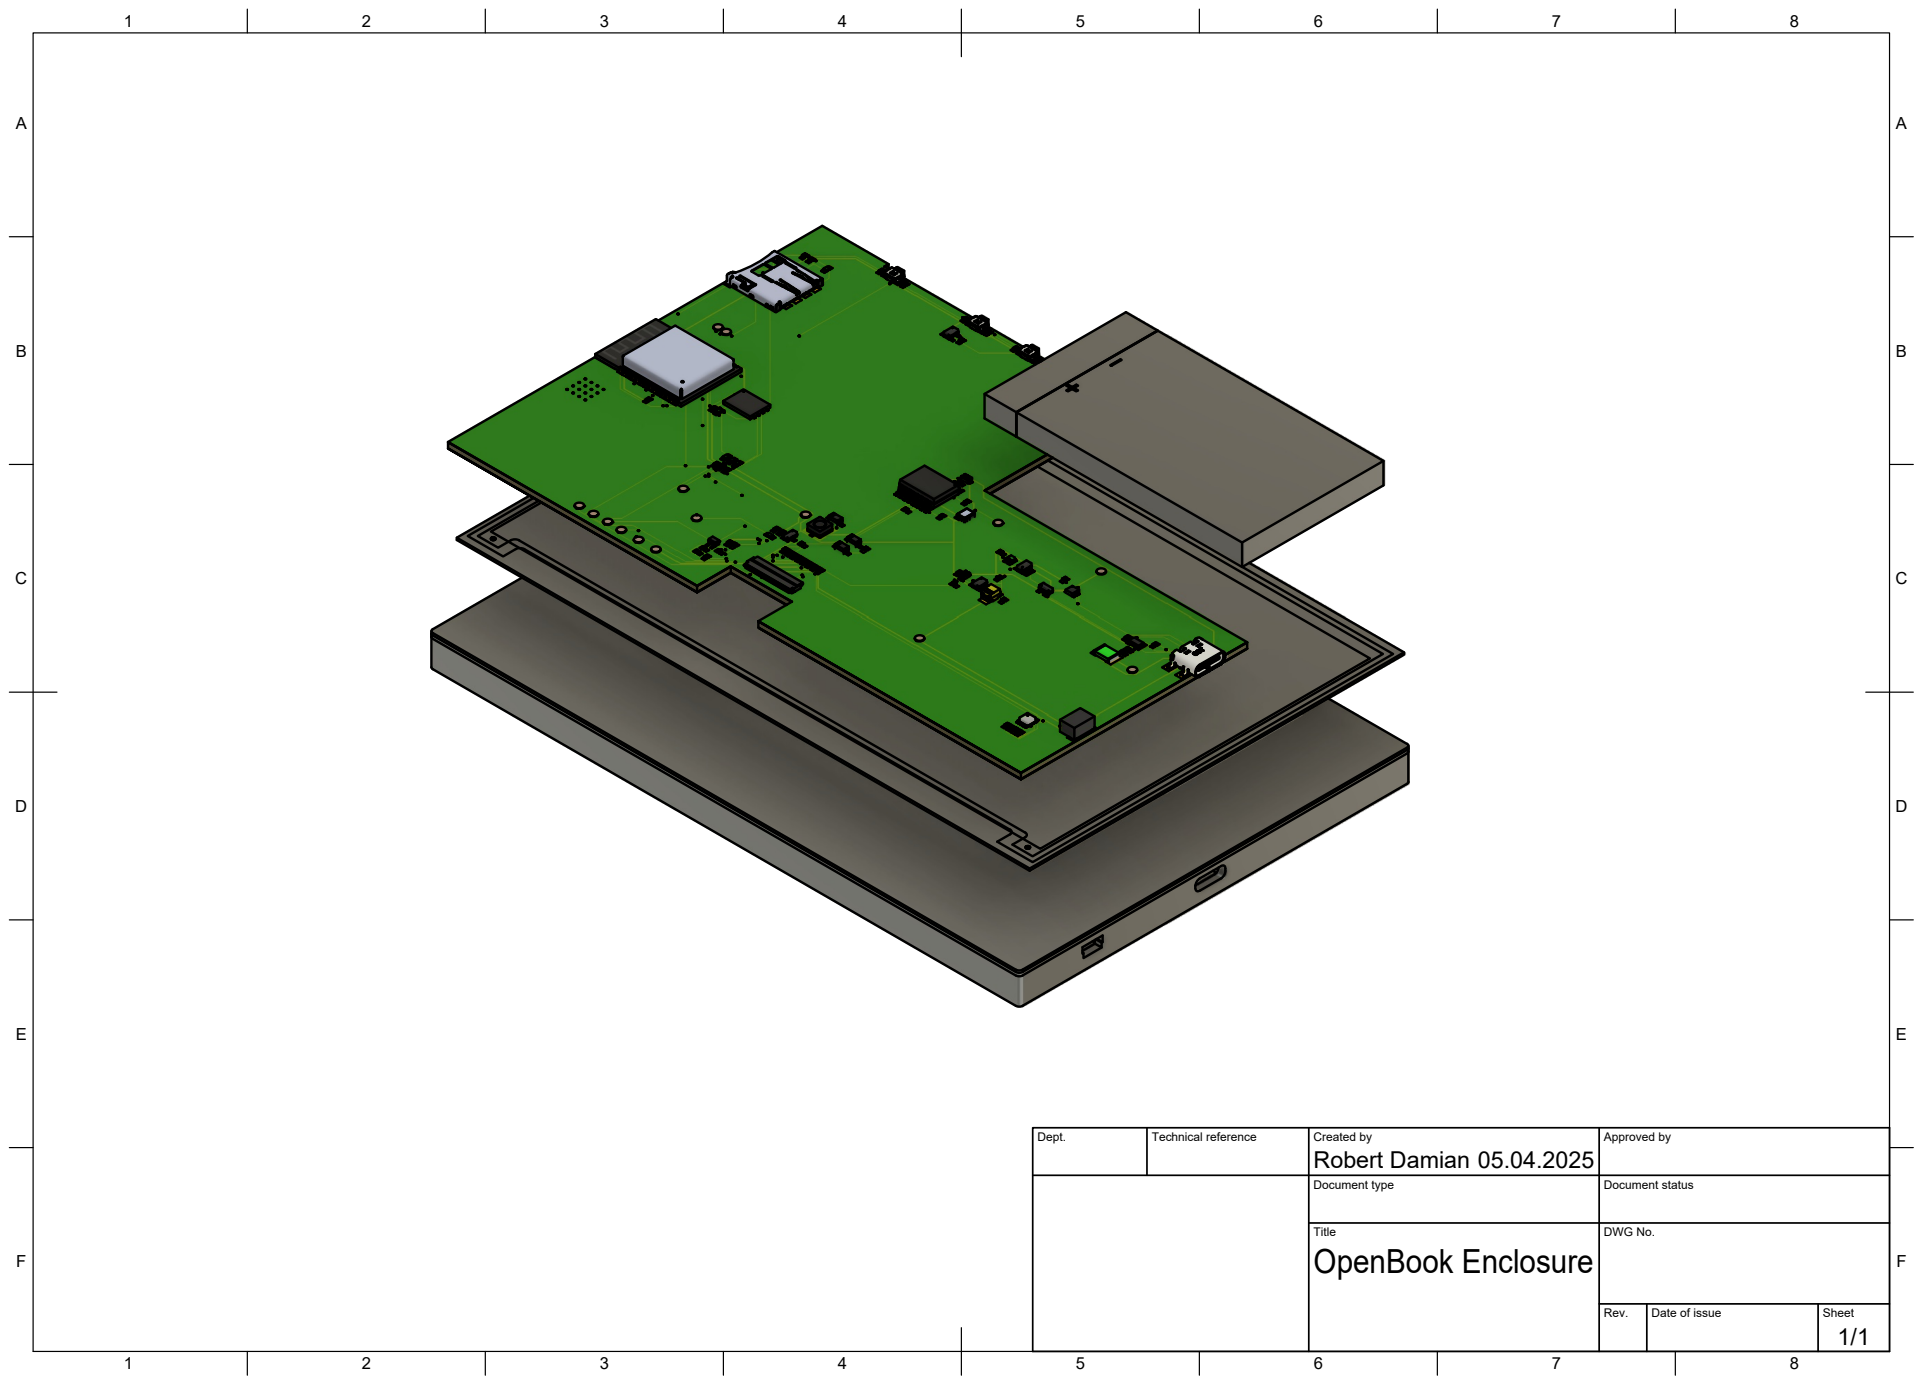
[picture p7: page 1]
Title; DWG No.; Rev.; Date of issue; Sheet; OpenBook Enclosure

Dept. | Technical reference | Created by Robert Damian 05.04.2025 | Approved by

Document type | Document status

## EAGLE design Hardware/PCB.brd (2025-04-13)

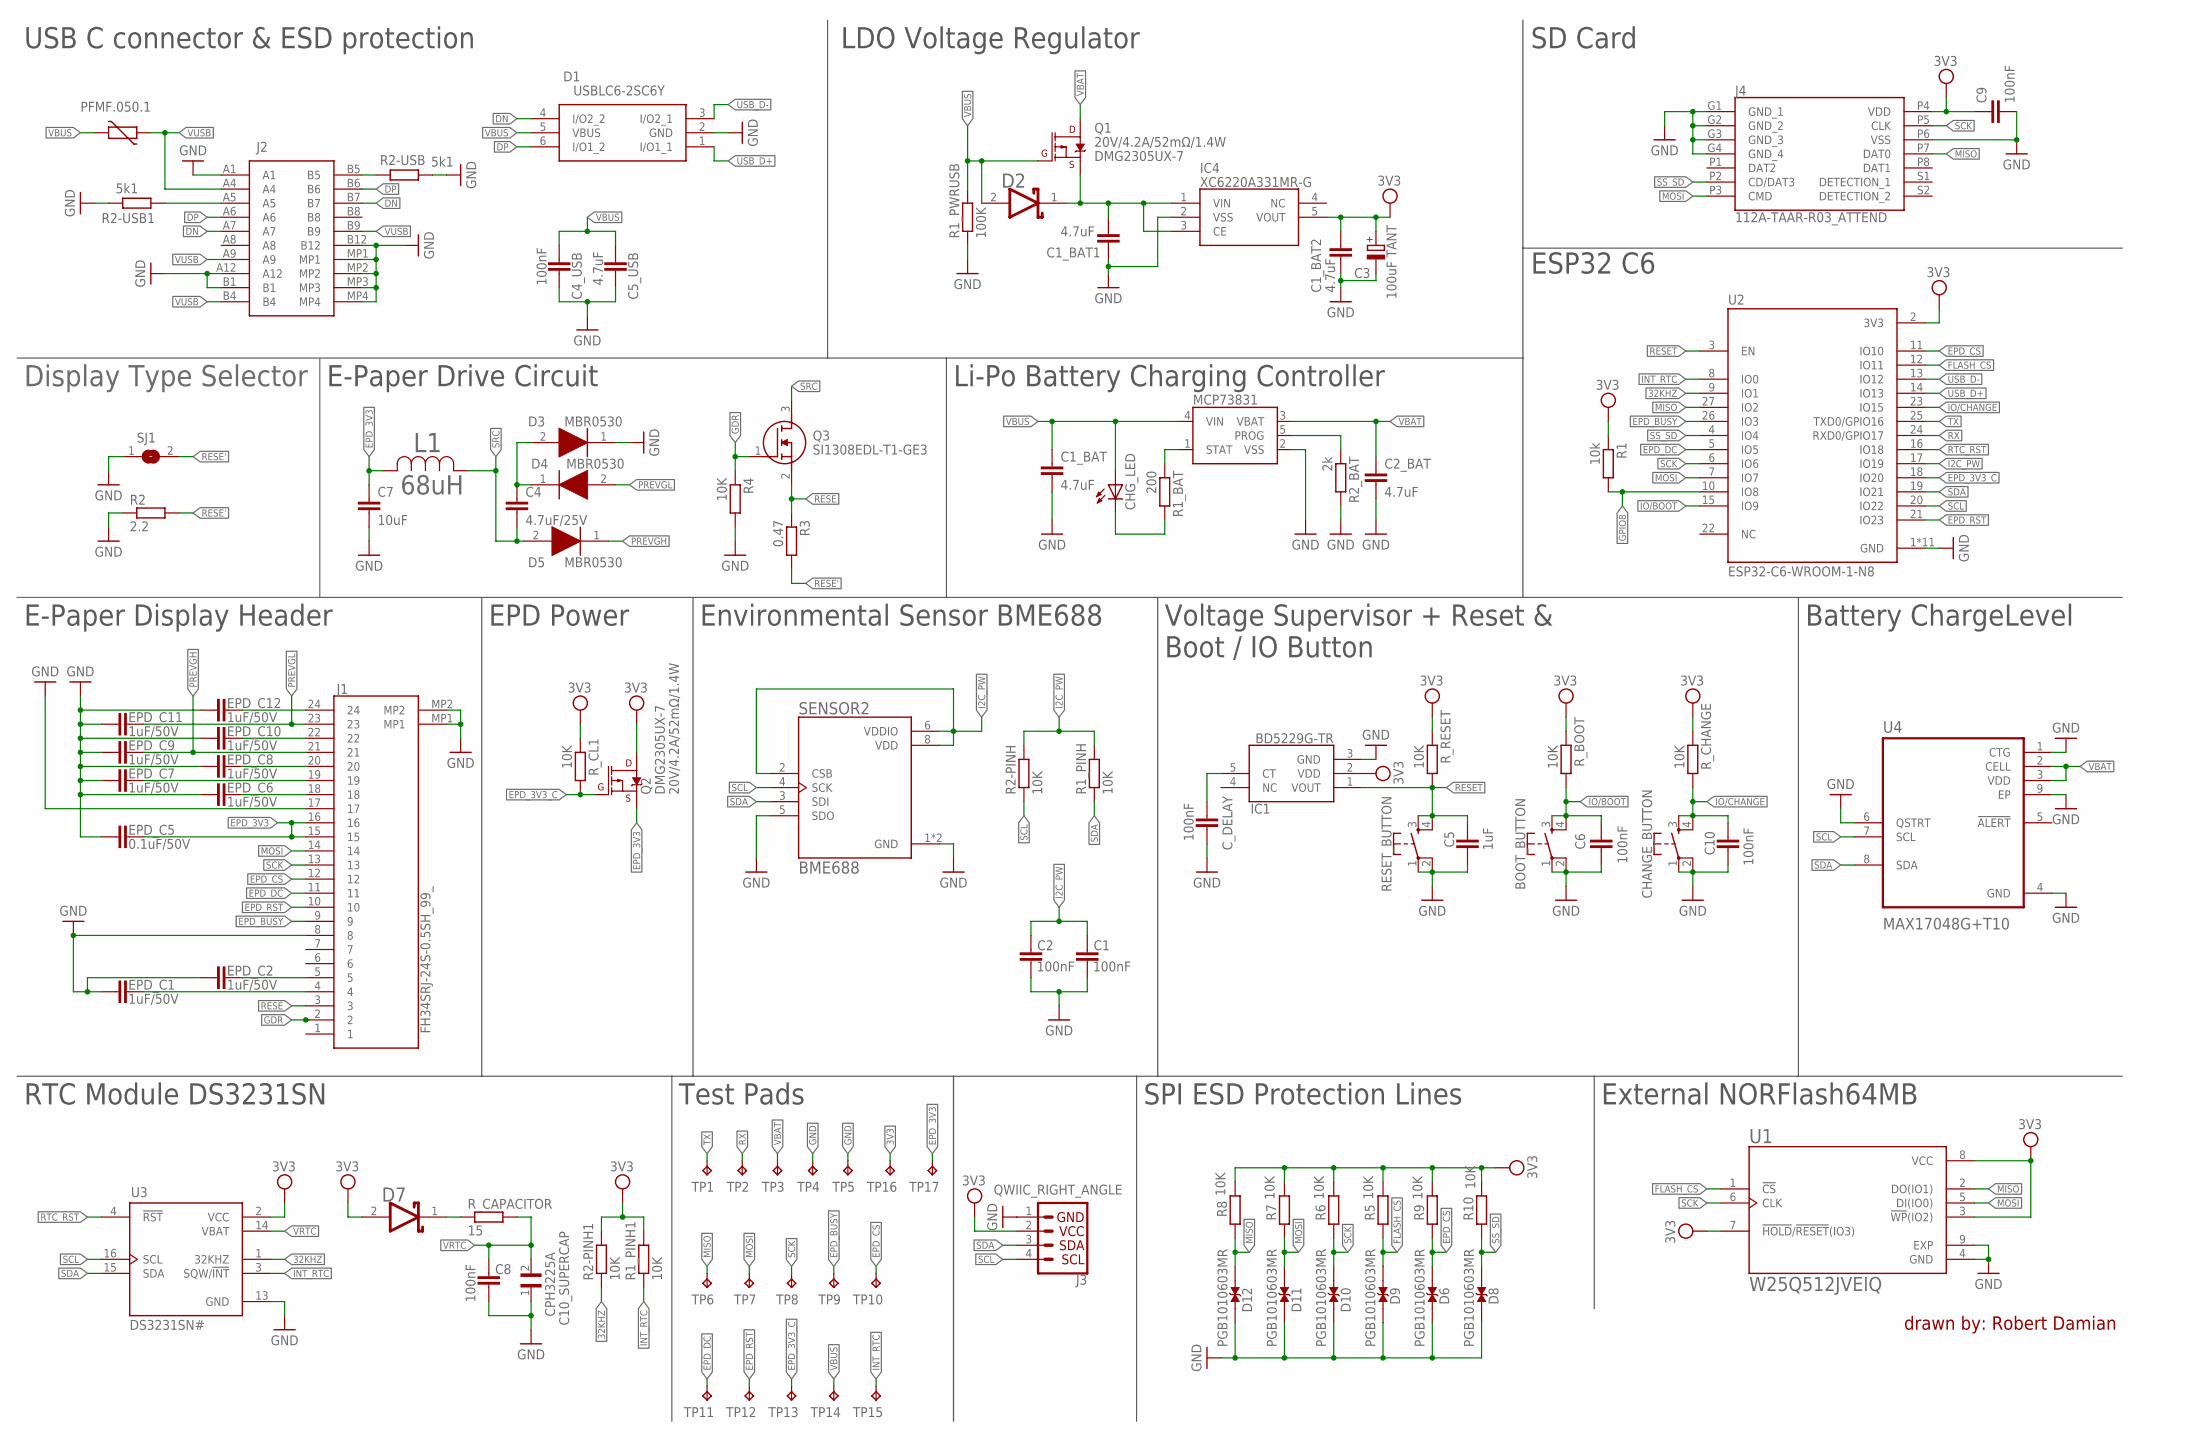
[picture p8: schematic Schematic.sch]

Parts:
BOOT_BUTTON: BUTTON_CUSYOMV1; MYBUTTON
C1, C2, C4_USB, C6, C8, C9, C10: 100nF; EAGLE-LTSPICE_C0402
C1_BAT, C1_BAT1, C1_BAT2, C2_BAT, C5_USB: 4.7uF; EAGLE-LTSPICE_C0402
C3: 100uF TANT; RCL_CT3528
C4: 4.7uF/25V; EAGLE-LTSPICE_C0402
C5: 1uF; EAGLE-LTSPICE_C0402
C7: 10uF; EAGLE-LTSPICE_C0402
C10_SUPERCAP: CPH3225A; CAPCP3225X100N
CHANGE_BUTTON: BUTTON_CUSYOMV1; MYBUTTON
CHG_LED: ADAFRUIT_LEDCHIP-LED0603; ADAFRUIT_CHIP-LED0603
C_DELAY: 100nF; EAGLE-LTSPICE_C0402
D1: USBLC6-2SC6Y; SOT95P280X145-6N
D2, D7: SD0805S020S1R0; ESP32_WROVER_AVX---SD0805S020S1R0_AVX_SD0805S020S1R0_0
D3, D4, D5: MBR0530; SOD3716X135N
D6, D8, D9, D10, D11, D12: PGB1010603MR; DIOC1608X36N
EPD_C1, EPD_C2, EPD_C6, EPD_C7, EPD_C8, EPD_C9, EPD_C10, EPD_C11, EPD_C12: 1uF/50V; EAGLE-LTSPICE_C0402
EPD_C5: 0.1uF/50V; EAGLE-LTSPICE_C0402
IC1: BD5229G-TR; SOT95P280X125-5N
IC4: XC6220A331MR-G; SOT95P280X120-5N
J1: FH34SRJ-24S-0.5SH_99_; FH34SRJ24S05SH99
J2: SAMACSYS_PARTS_USB4110-GF-A; SAMACSYS_PARTS_USB4110GFA
J3: QWIIC_RIGHT_ANGLE; JST04_1MM_RA
J4: 112A-TAAR-R03_ATTEND; 112ATAARR03ATTEND
L1: 68uH; IND_4828-WE-TPC_WRE
MCP73831: ESP32_WROVER_SPARKFUN-IC-POWER_MCP73831; ESP32_WROVER_SPARKFUN-IC-POWER_SOT23-5
PFMF.050.1: ESP32C6_VARISTORCN1812; ESP32C6_VARISTOR_CT/CN1812
Q1, Q2: 20V/4.2A/52mΩ/1.4W; ESP32_WROVER_SPARKFUN-DISCRETESEMI_SOT23-3
Q3: SI1308EDL-T1-GE3; SOT65P210X110-3N
R1: 10k; ESP32_WROVER_EAGLE-LTSPICE_R0402
R1_BAT: 200; ESP32_WROVER_EAGLE-LTSPICE_R0402
R1_PINH, R1_PINH1, R2-PINH, R2-PINH1, R4, R5, R6, R7, R8, R9, R10: 10K; ESP32_WROVER_EAGLE-LTSPICE_R0402
R1_PWRUSB: 100K; ESP32_WROVER_EAGLE-LTSPICE_R0402
R2: 2.2; ESP32_WROVER_EAGLE-LTSPICE_R0402
R2-USB, R2-USB1: 5k1; ESP32_WROVER_EAGLE-LTSPICE_R0402
R2_BAT: 2k; ESP32_WROVER_EAGLE-LTSPICE_R0402
R3: 0.47; ESP32_WROVER_EAGLE-LTSPICE_R0402
RESET_BUTTON: BUTTON_CUSYOMV1; MYBUTTON
R_BOOT: 10K; ESP32_WROVER_EAGLE-LTSPICE_R0402
R_CAPACITOR: 15; ESP32_WROVER_EAGLE-LTSPICE_R0402
R_CHANGE: 10K; ESP32_WROVER_EAGLE-LTSPICE_R0402
R_CL1: 10K; ESP32_WROVER_EAGLE-LTSPICE_R0402
R_RESET: 10K; ESP32_WROVER_EAGLE-LTSPICE_R0402
SENSOR2: BME688; ESP32_WROVER_BME680_PSON80P300X300X100-8N
SJ1: SJ; ESP32_WROVER_EAGLE-LTSPICE_R0402
TP1, TP2, TP3, TP4, TP5, TP6, TP7, TP8, TP9, TP10, TP11, TP12, TP13, TP14, TP15, TP16, TP17: TPTP20R; TP20R
U1: W25Q512JVEIQ; SON127P600X800X80-9N
U2: ESP32-C6-WROOM-1-N8; XCVR_ESP32-C6-WROOM-1-N8
U3: DS3231SN#; SOIC127P1032X265-16N
U4: MAX17048G+T10; SON50P200X200X80-9N

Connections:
3V3: C1_BAT2.1, C3.+, C9.1, D7.2 (ANODE), IC1.2 (VDD), IC4.5 (VOUT), J3.2, J4.P4 (VDD), Q2.3 (D), R1.1, R1_PINH1.2, R2-PINH1.2, R5.2, R6.2, R7.2, R8.2, R9.2, R10.2, R_BOOT.1, R_CHANGE.1, R_CL1.1, R_RESET.1, TP16.TP, U1.3 (!WP!(IO2)), U1.7 (!HOLD!/!RESET!(IO3)), U1.8 (VCC), U2.2 (3V3), U3.2 (VCC)
32KHZ: R2-PINH1.1, U2.9 (IO1), U3.1 (32KHZ)
DN: D1.4 (I/O2_2), J2.A7, J2.B7
DP: D1.6 (I/O1_2), J2.A6, J2.B6
EPD_3V3: C7.1, EPD_C5.1, J1.15, J1.16, L1.2, Q2.2 (S), TP17.TP
EPD_3V3_C: Q2.1 (G), R_CL1.2, TP13.TP, U2.18 (IO20)
EPD_BUSY: J1.9, TP9.TP, U2.26 (IO3)
EPD_CS: D6.1, J1.12, R9.1, TP10.TP, U2.11 (IO10)
EPD_DC: J1.11, TP11.TP, U2.5 (IO5)
EPD_RST: J1.10, TP12.TP, U2.21 (IO23)
FLASH_CS: D9.1, R5.1, U1.1 (!CS), U2.12 (IO11)
GDR: J1.2, Q3.1 (G), R4.1
GND: BOOT_BUTTON.1, BOOT_BUTTON.2, C1.2, C1_BAT.2, C1_BAT1.2, C1_BAT2.2, C2.2, C2_BAT.2, C3.-, C4_USB.2, C5.2, C5_USB.2, C6.2, C7.2, C8.2, C9.2, C10.2, C10_SUPERCAP.1, CHANGE_BUTTON.1, CHANGE_BUTTON.2, C_DELAY.2, D1.2 (GND), D3.1 (K), D6.2, D8.2, D9.2, D10.2, D11.2, D12.2, EPD_C1.2, EPD_C2.2, EPD_C5.2, EPD_C6.2, EPD_C7.2, EPD_C8.2, EPD_C9.2, EPD_C10.2, EPD_C11.2, EPD_C12.2, IC1.3 (GND), IC4.2 (VSS), J1.8, J1.17, J1.MP1, J1.MP2, J2.A1, J2.A12, J2.B1, J2.B12, J2.MP1, J2.MP2, J2.MP3, J2.MP4, J3.1, J4.G1 (GND_1), J4.G2 (GND_2), J4.G3 (GND_3), J4.G4 (GND_4), J4.P6 (VSS), MCP73831.2 (VSS), R1_PWRUSB.1, R2.1, R2-USB.1, R2-USB1.1, R2_BAT.2, R4.2, RESET_BUTTON.1, RESET_BUTTON.2, SENSOR2.1 (GND), SENSOR2.5 (SDO), SENSOR2.7 (GND), SJ1.1, TP4.TP, TP5.TP, U1.4 (GND), U1.9 (EXP), U2.1 (GND), U2.28 (GND), U2.29_1 (GND), U2.29_2 (GND), U2.29_3 (GND), U2.29_4 (GND), U2.29_5 (GND), U2.29_6 (GND), U2.29_7 (GND), U2.29_8 (GND), U2.29_9 (GND), U3.13 (GND), U4.1 (CTG), U4.4 (GND), U4.6 (QSTRT), U4.9 (EP)
GPIO8: R1.2, U2.10 (IO8)
I2C_PW: C1.1, C2.1, R1_PINH.2, R2-PINH.2, SENSOR2.2 (CSB), SENSOR2.6 (VDDIO), SENSOR2.8 (VDD), U2.17 (IO19)
INT_RTC: R1_PINH1.1, TP15.TP, U2.8 (IO0), U3.3 (SQW/!INT)
IO/BOOT: BOOT_BUTTON.3, BOOT_BUTTON.4, C6.1, R_BOOT.2, U2.15 (IO9)
IO/CHANGE: C10.1, CHANGE_BUTTON.3, CHANGE_BUTTON.4, R_CHANGE.2, U2.23 (IO15)
MISO: D12.1, J4.P7 (DAT0), R8.1, TP6.TP, U1.2 (DO(IO1)), U2.27 (IO2)
MOSI: D11.1, J1.14, J4.P3 (CMD), R7.1, TP7.TP, U1.5 (DI(IO0)), U2.7 (IO7)
unnamed: J2.A5, R2-USB1.2
unnamed: J2.B5, R2-USB.2
unnamed: EPD_C12.1, J1.24
unnamed: C1_BAT1.1, D2.1 (CATHODE), IC4.1 (VIN), IC4.3 (CE), Q1.2 (S)
unnamed: CHG_LED.C, R1_BAT.2
unnamed: C4.1, D3.2 (A), D4.1 (K)
unnamed: MCP73831.1 (STAT), R1_BAT.1
unnamed: MCP73831.5 (PROG), R2_BAT.1
unnamed: EPD_C2.1, J1.5
unnamed: EPD_C10.1, J1.22
unnamed: EPD_C1.1, J1.4
unnamed: EPD_C8.1, J1.20
unnamed: EPD_C7.1, J1.19
unnamed: EPD_C6.1, J1.18
unnamed: C_DELAY.1, IC1.5 (CT)
unnamed: D7.1 (CATHODE), R_CAPACITOR.1
PREVGH: D5.1 (K), EPD_C9.1, J1.21
PREVGL: D4.2 (A), EPD_C11.1, J1.23
RESE: J1.3, Q3.2 (S), R3.1
RESE': R2.2, R3.2, SJ1.2
RESET: C5.1, IC1.1 (VOUT), RESET_BUTTON.3, RESET_BUTTON.4, R_RESET.2, U2.3 (EN)
RTC_RST: U2.16 (IO18), U3.4 (!RST)
RX: TP2.TP, U2.24 (RXD0/GPIO17)
SCK: D10.1, J1.13, J4.P5 (CLK), R6.1, TP8.TP, U1.6 (CLK), U2.6 (IO6)
SCL: J3.4, R2-PINH.1, SENSOR2.4 (SCK), U2.20 (IO22), U3.16 (SCL), U4.7 (SCL)
SDA: J3.3, R1_PINH.1, SENSOR2.3 (SDI), U2.19 (IO21), U3.15 (SDA), U4.8 (SDA)
SRC: C4.2, D5.2 (A), L1.1, Q3.3 (D)
SS_SD: D8.1, J4.P2 (CD/DAT3), R10.1, U2.4 (IO4)
TX: TP1.TP, U2.25 (TXD0/GPIO16)
USB_D+: D1.1 (I/O1_1), U2.14 (IO13)
USB_D-: D1.3 (I/O2_1), U2.13 (IO12)
VBAT: C2_BAT.1, MCP73831.3 (VBAT), Q1.3 (D), TP3.TP, U4.2 (CELL), U4.3 (VDD)
VBUS: C1_BAT.1, C4_USB.1, C5_USB.1, CHG_LED.A, D1.5 (VBUS), D2.2 (ANODE), MCP73831.4 (VIN), PFMF.050.1.2, Q1.1 (G), R1_PWRUSB.2, TP14.TP
VRTC: C8.1, C10_SUPERCAP.2, R_CAPACITOR.2, U3.14 (VBAT)
VUSB: J2.A4, J2.A9, J2.B4, J2.B9, PFMF.050.1.1

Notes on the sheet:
USB C connector & ESD protection
LDO Voltage Regulator
SD Card
ESP32 C6
Display Type Selector
E-Paper Drive Circuit
Li-Po Battery Charging Controller
E-Paper Display Header
EPD Power
Environmental Sensor BME688
Voltage Supervisor + Reset & Boot / IO Button
Battery ChargeLevel
RTC Module DS3231SN
Test Pads
SPI ESD Protection Lines
External NORFlash64MB
DMG2305UX-7
drawn by: Robert Damian

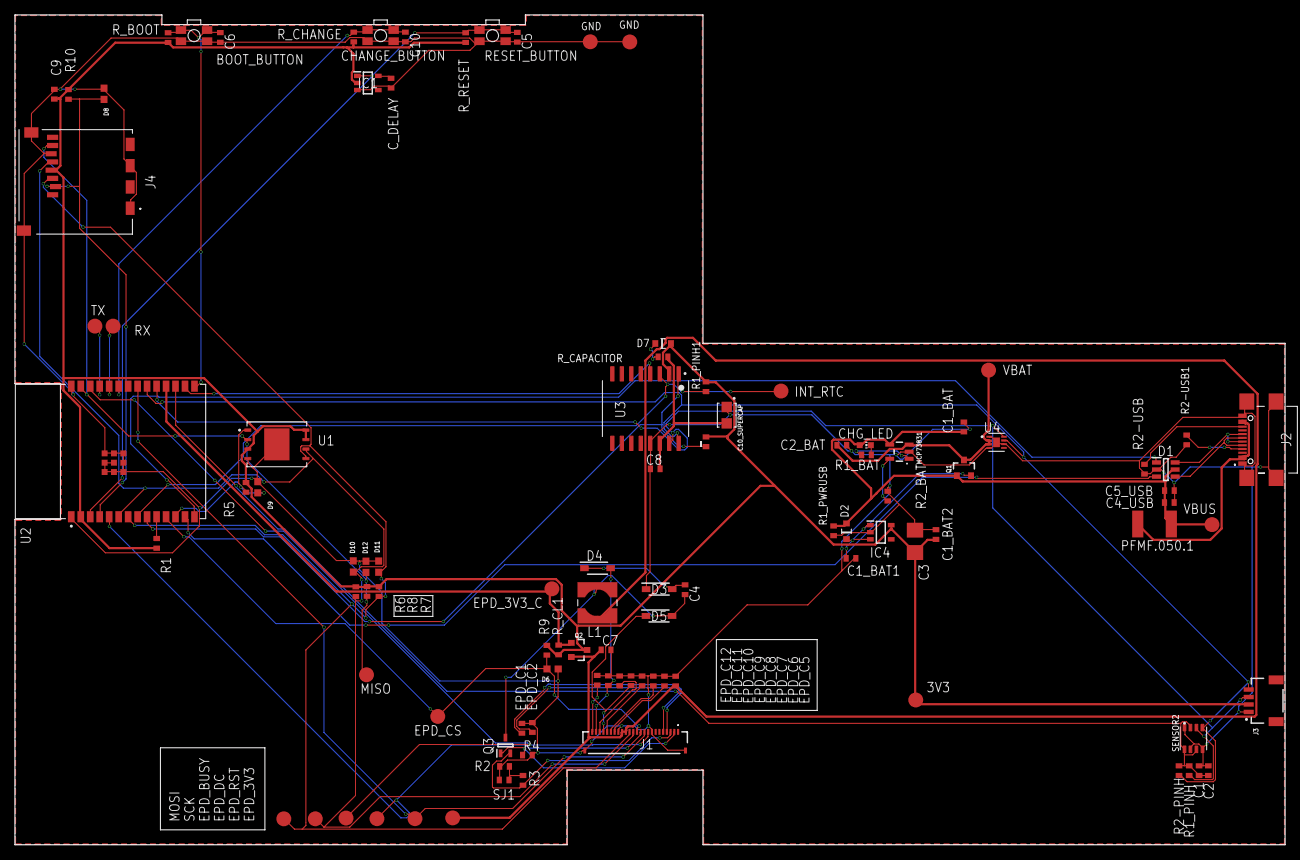
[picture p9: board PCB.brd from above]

Board: 2 copper layers, 170.2 x 111.2 mm, 103 parts (0 on the bottom side), 55 nets.

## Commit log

2025-04-05 Finished model, missing README
    [PickAndPlace.csv, Proiect_TSC_v41.brd, bom.csv]
2025-04-06 Updated Hardware
    [PCB.brd, Schematic.sch]
2025-04-13 Solved all issues
    [PCB.brd, Schematic.sch]

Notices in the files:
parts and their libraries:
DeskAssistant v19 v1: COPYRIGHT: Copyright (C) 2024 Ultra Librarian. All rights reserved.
